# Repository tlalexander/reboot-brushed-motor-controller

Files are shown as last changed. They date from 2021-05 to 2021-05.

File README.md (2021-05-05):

Brushed Motor Controller by Taylor Alexander from reboot.love

NOTICE: I would love it if someone wanted to manufacture these for their own profit. I have licensed everything CC0 which means I release all rights. I just want someone to make these! The current design works but can be improved. If anyone wants to produce these, please email me and we can collaborate on improving the design.

Purpose:

There are lots of low cost (under $10) brushed gear motors with encoders on Aliexpress and Amazon. This board is designed to precisely drive those motors, using encoder feedback and current measurement for precise positioning, velocity, and current control.

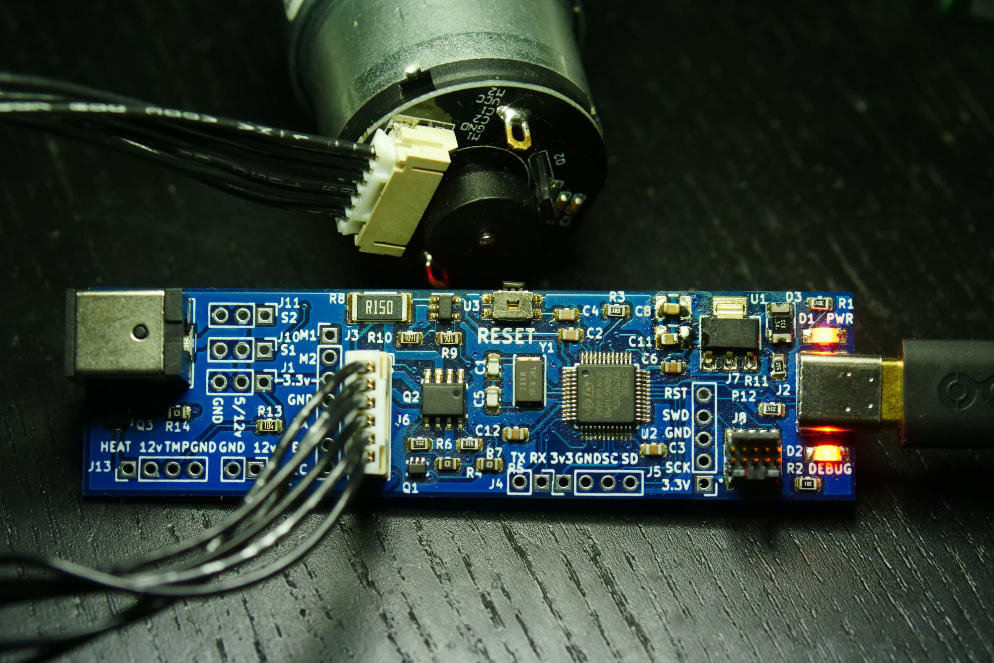
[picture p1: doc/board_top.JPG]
Board Top Photo board top photo

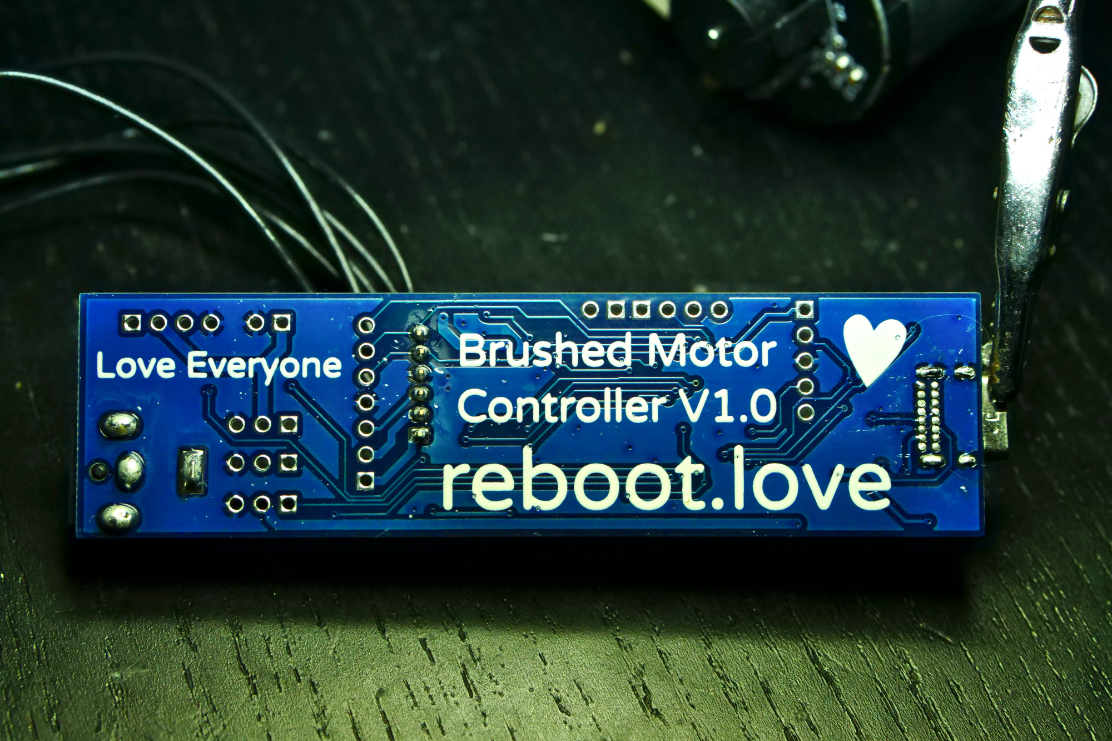
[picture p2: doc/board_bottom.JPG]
Board Bottom Photo board bottom photo


Possible improvements:
Q1 is a little small physically.
Form factor could be improved.
J1, J10, J11 could be removed, along with Q3.
Should check motor pinouts and compare to common motors.

License Notes:
This board is heavily modified from David Grubb's Jaguar-USB-tap.
https://github.com/dgrubb/Jaguar-USB-tap
That board has a GPL license. When I emailed David for permission to relicense as CC0, he replied "I don't think you need my permission."
So I am relicensing CC0 as I tend to prefer that type of license. If you have any concerns over licensing, contact David Grubb or consider following the more restrictive GPL V3.0 License (meaning: share your modifications and everything will be fine).

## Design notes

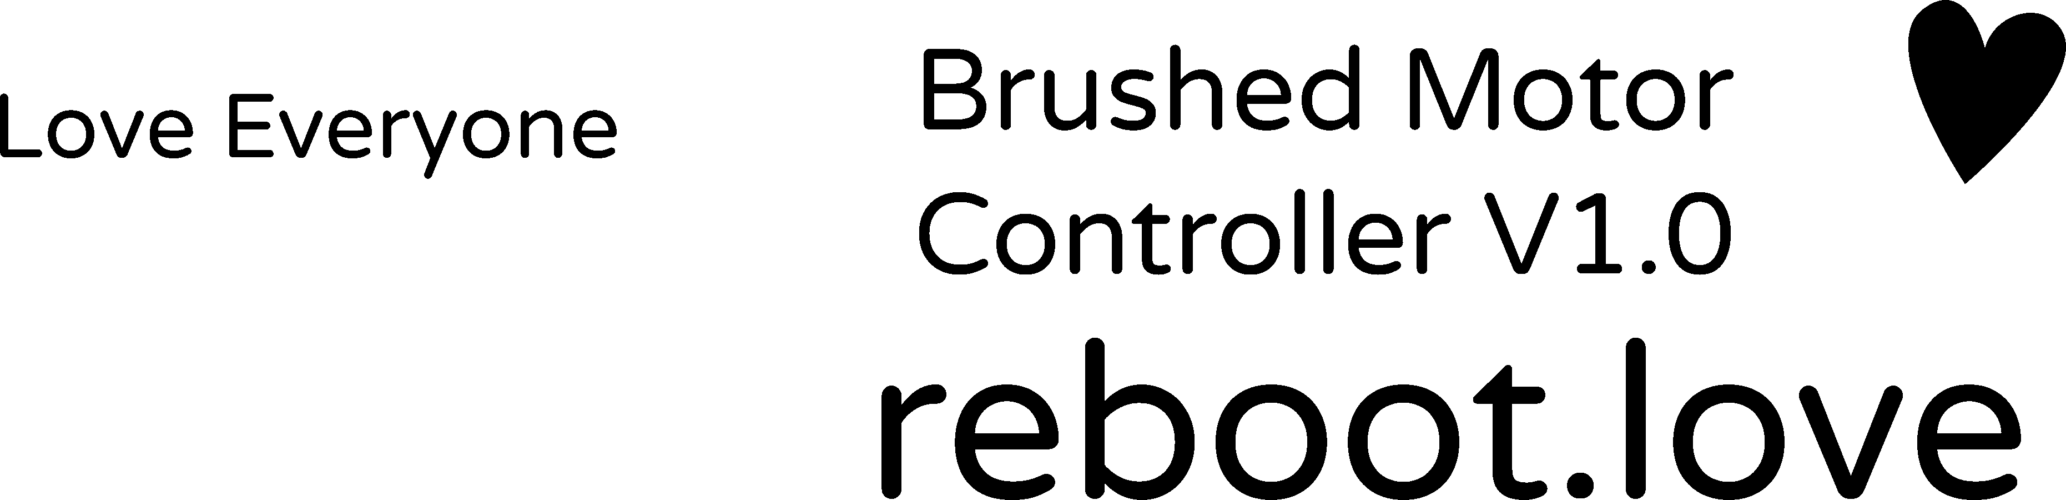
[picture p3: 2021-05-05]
hardware/artwork/cleaned_up.bmp

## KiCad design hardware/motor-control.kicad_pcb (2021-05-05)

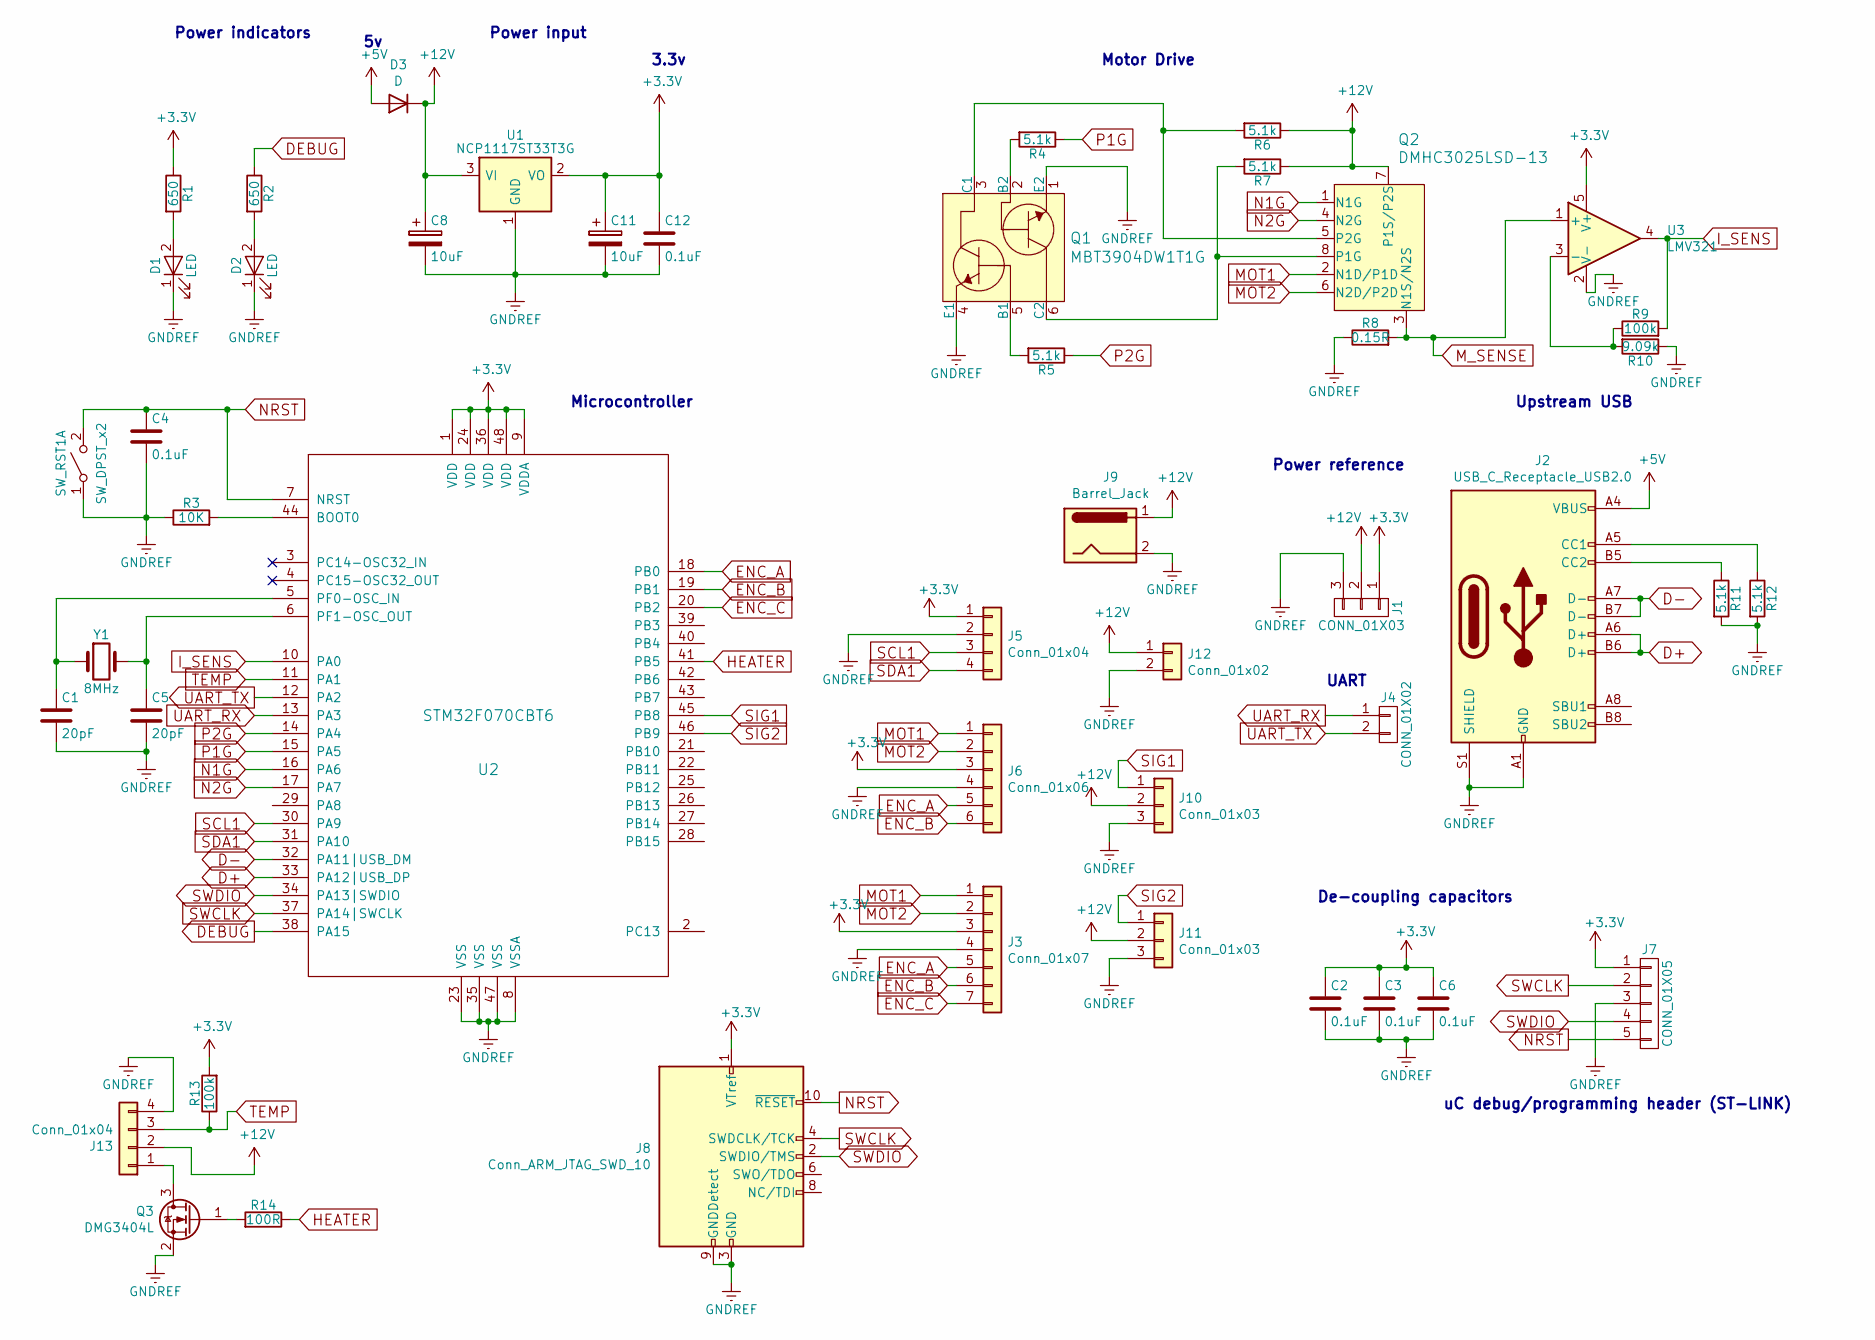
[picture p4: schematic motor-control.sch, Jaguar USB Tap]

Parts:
C1, C5: 20pF; C_0805_2012Metric
C2, C3, C4, C6, C12: 0.1uF; C_0805_2012Metric
C8, C11: 10uF; C_1210_3225Metric
D1, D2: LED; LED_1206
D3: D; D_1210_3225Metric
J1: CONN_01X03; Pin_Header_Straight_1x03_Pitch2.54mm
J2: USB_C_Receptacle_USB2.0; USB_C_Receptacle_GCT_USB4085
J3: Conn_01x07; PinHeader_1x07_P2.54mm_Vertical
J4: CONN_01X02; PinHeader_1x02_P2.54mm_Vertical
J5, J13: Conn_01x04; PinHeader_1x04_P2.54mm_Vertical
J6: Conn_01x06; JST_PH_B6B-PH-K_1x06_P2.00mm_Vertical
J7: CONN_01X05; PinHeader_1x05_P2.54mm_Vertical
J8: Conn_ARM_JTAG_SWD_10; SAMTEC_FTSH-105-01-L-DV-K
J9: Barrel_Jack; BarrelJack_CUI_PJ-063AH_Horizontal
J10, J11: Conn_01x03; PinHeader_1x03_P2.54mm_Vertical
J12: Conn_01x02; PinHeader_1x02_P2.54mm_Vertical
Q1: MBT3904DW1T1G; SOT-363; MPN MBT3904DW1T1G; Digi-Key_PN MBT3904DW1T1GOSCT-ND
Q2: DMHC3025LSD-13; SOIC-8_W3.9mm; MPN DMHC3025LSD-13; Digi-Key_PN DMHC3025LSD-13DICT-ND
Q3: DMG3404L; SOT-23
R1, R2: 650; R_0805_2012Metric
R3: 10K; R_0805_2012Metric
R4, R5, R6, R7, R11, R12: 5.1k; R_0805_2012Metric
R8: 0.15R; R_2512_6332Metric
R9, R13: 100k; R_0805_2012Metric
R10: 9.09k; R_0805_2012Metric
R14: 100R; R_0805_2012Metric
SW_RST1: SW_DPST_x2; Panasonic_EVQPUK_EVQPUB
U1: NCP1117ST33T3G; SOT-223
U2: STM32F070CBT6; LQFP-48_7x7mm_Pitch0.5mm
U3: LMV321; SOT-23-5
Y1: 8MHz; Crystal_SMD_5032-2Pin_5.0x3.2mm

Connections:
+3V3: C2.1, C3.1, C6.1, C11.1, C12.1, J1.1, J3.3, J5.1, J6.3, J7.1, J8.1 (VTref), R1.1, R13.2, U1.2 (VO), U2.1 (VDD), U2.9 (VDDA), U2.24 (VDD), U2.36 (VDD), U2.48 (VDD), U3.5 (V+)
+5V: D3.2 (A), J2.A4 (VBUS), J2.A9 (VBUS), J2.B4 (VBUS), J2.B9 (VBUS)
+12V: C8.1, D3.1 (K), J1.2, J9.1, J10.2, J11.2, J12.1, J13.2, Q2.7 (P1S/P2S), R6.1, R7.1, U1.3 (VI)
D+: J2.A6 (D+), J2.B6 (D+), U2.33 (PA12|USB_DP)
D-: J2.A7 (D-), J2.B7 (D-), U2.32 (PA11|USB_DM)
DEBUG: R2.1, U2.38 (PA15)
ENC_A: J3.5, J6.5, U2.18 (PB0)
ENC_B: J3.6, J6.6, U2.19 (PB1)
ENC_C: J3.7, U2.20 (PB2)
GNDREF: C1.2, C2.2, C3.2, C4.2, C5.2, C6.2, C8.2, C11.2, C12.2, D1.1 (K), D2.1 (K), J1.3, J2.A1 (GND), J2.A12 (GND), J2.B1 (GND), J2.B12 (GND), J2.S1 (SHIELD), J3.4, J5.2, J6.4, J7.3, J8.3 (GND), J8.5 (GND), J8.9 (GNDDetect), J9.2, J10.3, J11.3, J12.2, J13.4, Q1.1 (E2), Q1.4 (E1), Q3.2 (S), R3.1, R8.1, R10.1, R11.2, R12.2, SW_RST1.1 (A), U1.1 (GND), U2.8 (VSSA), U2.23 (VSS), U2.35 (VSS), U2.47 (VSS), U3.2 (V-)
HEATER: R14.1, U2.41 (PB5)
I_SENS: R9.2, U2.10 (PA0), U3.4
MOT1: J3.1, J6.1, Q2.2 (N1D/P1D)
MOT2: J3.2, J6.2, Q2.6 (N2D/P2D)
M_SENSE: Q2.3 (N1S/N2S), R8.2, U3.1 (+)
N1G: Q2.1 (N1G), U2.16 (PA6)
N2G: Q2.4 (N2G), U2.17 (PA7)
NRST: C4.1, J7.5, J8.10 (~RESET~), SW_RST1.2 (B), U2.7 (NRST)
unnamed: C1.1, U2.5 (PF0-OSC_IN), Y1.1
unnamed: C5.1, U2.6 (PF1-OSC_OUT), Y1.2
unnamed: D1.2 (A), R1.2
unnamed: D2.2 (A), R2.2
unnamed: J2.A5 (CC1), R12.1
unnamed: J2.B5 (CC2), R11.1
unnamed: J13.1, Q3.3 (D)
unnamed: Q1.2 (B2), R4.2
unnamed: Q1.3 (C1), Q2.5 (P2G), R6.2
unnamed: Q1.5 (B1), R5.2
unnamed: Q1.6 (C2), Q2.8 (P1G~), R7.2
unnamed: Q3.1 (G), R14.2
unnamed: R3.2, U2.44 (BOOT0)
unnamed: R9.1, R10.2, U3.3 (-)
P1G: R5.1, U2.14 (PA4)
P2G: R4.1, U2.15 (PA5)
SCL1: J5.3, U2.30 (PA9)
SDA1: J5.4, U2.31 (PA10)
SIG1: J10.1, U2.45 (PB8)
SIG2: J11.1, U2.46 (PB9)
SWCLK: J7.2, J8.4 (SWDCLK/TCK), U2.37 (PA14|SWCLK)
SWDIO: J7.4, J8.2 (SWDIO/TMS), U2.34 (PA13|SWDIO)
TEMP: J13.3, R13.1, U2.11 (PA1)
UART_RX: J4.1, U2.13 (PA3)
UART_TX: J4.2, U2.12 (PA2)

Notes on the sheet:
Power indicators
Power input
3.3v
Power reference
Upstream USB
uC debug/programming header (ST-LINK)
UART
De-coupling capacitors
Microcontroller
Motor Drive

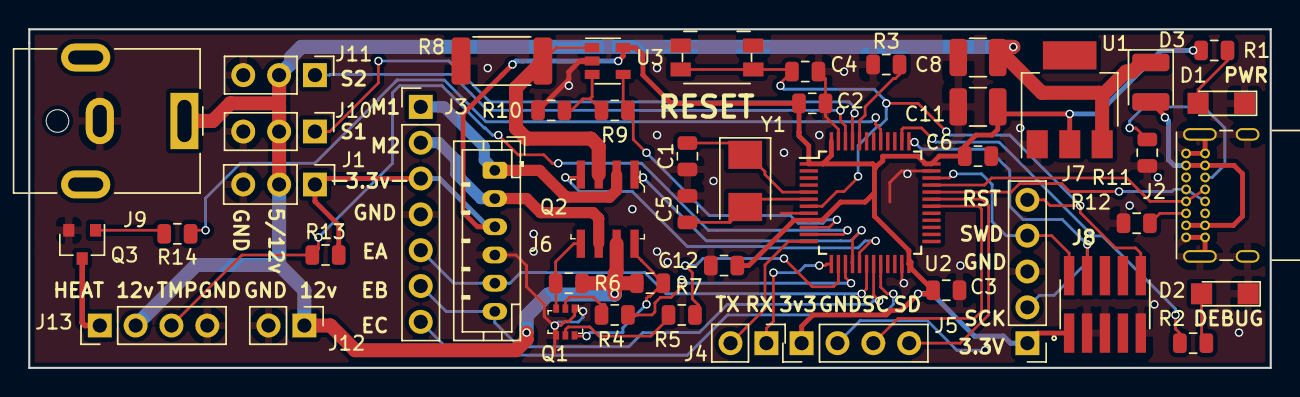
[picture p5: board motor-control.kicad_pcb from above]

Board: 2 copper layers, 88.0 x 24.0 mm, 47 parts (0 on the bottom side), 43 nets.

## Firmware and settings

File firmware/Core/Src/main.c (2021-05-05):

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
/* Includes ------------------------------------------------------------------*/
#include "main.h"
#include "usb_device.h"

ADC_HandleTypeDef hadc;

TIM_HandleTypeDef htim1;
TIM_HandleTypeDef htim3;

UART_HandleTypeDef huart1;

/* USER CODE BEGIN PV */

volatile uint32_t enc_a_count = 0;
volatile uint32_t enc_b_count = 0;
volatile uint32_t enc_c_count = 0;

/* USER CODE END PV */

void SystemClock_Config(void);
static void MX_GPIO_Init(void);
static void MX_ADC_Init(void);
static void MX_TIM1_Init(void);
static void MX_TIM3_Init(void);
static void MX_USART1_UART_Init(void);
static void MX_NVIC_Init(void);
/**
  * @brief  The application entry point.
  * @retval int
  */
int main(void)
{
  /* MCU Configuration--------------------------------------------------------*/

  /* Reset of all peripherals, Initializes the Flash interface and the Systick. */
  HAL_Init();

  /* Configure the system clock */
  SystemClock_Config();

  /* Initialize all configured peripherals */
  MX_GPIO_Init();
  MX_ADC_Init();
  MX_TIM1_Init();
  MX_TIM3_Init();
  MX_USART1_UART_Init();
  MX_USB_DEVICE_Init();

  /* Initialize interrupts */
  MX_NVIC_Init();
  /* Infinite loop */
  /* USER CODE BEGIN WHILE */
  uint8_t* Buf [20];
  uint16_t Len = 5;

  int dutyCycle = 0;

  CDC_Transmit_FS("USB START\n", 10);

  HAL_Delay(5000);




  HAL_TIM_PWM_Start(&htim3, TIM_CHANNEL_1);    //starts PWM on CH2 pin
  HAL_GPIO_WritePin(GPIOA, GPIO_PIN_4, GPIO_PIN_RESET);

  HAL_TIM_PWM_Start(&htim3, TIM_CHANNEL_2);    //starts PWM on CH2 pin
  HAL_GPIO_WritePin(GPIOA, GPIO_PIN_5, GPIO_PIN_RESET);

  HAL_ADCEx_Calibration_Start(&hadc);

  HAL_ADC_Start(&hadc);
  uint16_t current_sense = 0;

  int increment = 2000;
  uint8_t usb_buffer [100];
  uint32_t loop_count = 0;
  uint32_t loop_limit = 20;
  uint32_t speed = 0;
  while (1)
  {
    loop_count+=1;
    /* USER CODE END WHILE */

    /* USER CODE BEGIN 3 */

    int count = VCP_read(&usb_buffer, 10);

    if(count>0)
    {
      Len = sprintf (Buf, "count: %d\n", count);
      CDC_Transmit_FS(Buf, Len);
      HAL_Delay(1);
      CDC_Transmit_FS(usb_buffer, count);
    }
    //
    int i;
    for(i=0;i<100;i++)
    {

      if(usb_buffer[i]=='B')
      {
      HAL_Delay(1);
        CDC_Transmit_FS("GOT B\n", 6);
        dutyCycle = 60000;
      }
      if(usb_buffer[i]=='N')
      {
      HAL_Delay(1);
        CDC_Transmit_FS("GOT N\n", 6);
        dutyCycle = -1;
      }
      usb_buffer[i] = 0;
    }

      HAL_Delay(1);
      //dutyCycle+=increment;
      if(dutyCycle>64000)
      {
        increment *= -1;
      }
      if(dutyCycle<-64000)
      {
        increment *= -1;
      }

      if(dutyCycle > 0)
      {

        HAL_GPIO_WritePin(GPIOA, GPIO_PIN_5, GPIO_PIN_RESET);
        __HAL_TIM_SET_COMPARE(&htim3, TIM_CHANNEL_2, 0); //sets the PWM duty cycle (Capture Compare Value
          HAL_Delay(1);
        HAL_GPIO_WritePin(GPIOA, GPIO_PIN_4, GPIO_PIN_SET);
        __HAL_TIM_SET_COMPARE(&htim3, TIM_CHANNEL_1, dutyCycle); //sets the PWM duty cycle (Capture Compare Value
      }
      else{

          HAL_GPIO_WritePin(GPIOA, GPIO_PIN_4, GPIO_PIN_RESET);
        __HAL_TIM_SET_COMPARE(&htim3, TIM_CHANNEL_1, 0); //sets the PWM duty cycle (Capture Compare Value
          HAL_Delay(1);
          HAL_GPIO_WritePin(GPIOA, GPIO_PIN_5, GPIO_PIN_SET);
        __HAL_TIM_SET_COMPARE(&htim3, TIM_CHANNEL_2, -dutyCycle); //sets the PWM duty cycle (Capture Compare Value
      }
      HAL_ADC_Start(&hadc);
      // Poll ADC1 Perihperal & TimeOut = 1mSec
      HAL_ADC_PollForConversion(&hadc, 0);
      current_sense = HAL_ADC_GetValue(&hadc);

      // HAL_ADC_PollForConversion(&hadc, 1);
      // HAL_ADC_GetValue(&hadc);
      if(loop_count > loop_limit)
      {
        loop_count = 0;
        speed = enc_a_count;
        Len = sprintf (Buf, "current: %d\n", speed);
        CDC_Transmit_FS(Buf, Len);
        enc_a_count = 0;
      }

      // if(speed > 8)
      // {
      //   dutyCycle-= 100;
      // }
      // if(speed < 6)
      // {
      //   dutyCycle+= 100;
      //
      // }
      // if(dutyCycle > 64000) dutyCycle=64000;
      // if(dutyCycle < 1) dutyCycle=1;


      //CDC_Putc(usb_buffer);



      // HAL_GPIO_WritePin(GPIOA, GPIO_PIN_6, GPIO_PIN_SET);
      // HAL_GPIO_WritePin(GPIOA, GPIO_PIN_4, GPIO_PIN_SET);
      // HAL_Delay(50);
      //

      // HAL_GPIO_WritePin(GPIOA, GPIO_PIN_6, GPIO_PIN_RESET);
      // HAL_GPIO_WritePin(GPIOA, GPIO_PIN_4, GPIO_PIN_RESET);
      // HAL_Delay(50);


  }
  /* USER CODE END 3 */
}

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
/* USER CODE BEGIN 4 */
void HAL_GPIO_EXTI_Callback(uint16_t GPIO_Pin)
{
  switch (GPIO_Pin)
 {
     case ENC_A_Pin: enc_a_count += 1; break;
     case ENC_B_Pin: enc_b_count += 1; break;
     case ENC_C_Pin: enc_c_count += 1; break;
 }
}

/* USER CODE END 4 */
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


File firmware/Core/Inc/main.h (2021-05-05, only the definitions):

#define ENC_A_Pin GPIO_PIN_0
#define ENC_A_GPIO_Port GPIOB
#define ENC_A_EXTI_IRQn EXTI0_1_IRQn
#define ENC_B_Pin GPIO_PIN_1
#define ENC_B_GPIO_Port GPIOB
#define ENC_B_EXTI_IRQn EXTI0_1_IRQn
#define ENC_C_Pin GPIO_PIN_2
#define ENC_C_GPIO_Port GPIOB
#define ENC_C_EXTI_IRQn EXTI2_3_IRQn

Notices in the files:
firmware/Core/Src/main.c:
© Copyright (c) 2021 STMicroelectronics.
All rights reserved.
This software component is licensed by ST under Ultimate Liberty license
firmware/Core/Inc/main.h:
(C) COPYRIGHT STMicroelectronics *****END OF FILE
